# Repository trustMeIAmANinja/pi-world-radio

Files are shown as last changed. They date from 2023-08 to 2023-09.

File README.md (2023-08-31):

# Raspberry Pi Retro World Radio

<picture>
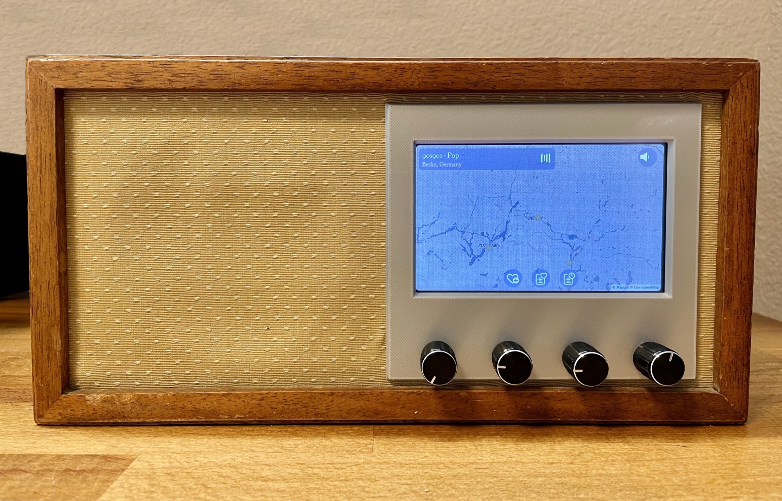
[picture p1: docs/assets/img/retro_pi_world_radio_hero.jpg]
  
</picture>

## What is this?

A retro radio to tune-in to streaming stations from around the world.

## Looking for Docs?

The build docs are here: [https://trustmeiamaninja.github.io/pi-world-radio](https://trustmeiamaninja.github.io/pi-world-radio)

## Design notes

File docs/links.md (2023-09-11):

# Links

A collection of websites and other resources used.

 - [Raspberry Pi OS Docs](https://www.raspberrypi.com/documentation/computers/getting-started.html#installing-the-operating-system ':target=_blank')
    - [Installing the OS](https://www.raspberrypi.com/documentation/computers/getting-started.html#installing-the-operating-system ':target=_blank')
 - [Dave Steele's Comitup - Headless Wifi Manager for Raspberry Pi](https://davesteele.github.io/comitup/ ':target=_blank')
 - [Raspberry Pi OS dtoverlay](https://www.raspberrypi.com/documentation/computers/configuration.html#part3 ':target=_blank')
 - [zram Config to extend life of the SD Card](https://github.com/ecdye/zram-config ':target=_blank')
 - [Raspberry Pi GPIO Pinout @ Pinout.xyz](https://pinout.xyz/ ':target=_blank')
 - [Henryk Plötz's superb article on using a rotary encoder](https://blog.ploetzli.ch/2018/ky-040-rotary-encoder-linux-raspberry-pi/ ':target=_blank')
 - [Raspiaudio HAT Installation Guide](https://forum.raspiaudio.com/t/mic-installation-guide/17 ':target=_blank')
    - [Raspiaudio Pinout](https://pinout.xyz/pinout/raspiaudio_audio_speakers_mic ':target=_blank')
 - [Elecrow Wiki page for the 5" display](https://elecrow.com/wiki/index.php?title=HDMI_Interface_5_Inch_800x480_TFT_Display ':target=_blank')
 - [Minimal Install for running Chromium in Kiosk Mode by Sylvain Durand](https://sylvaindurand.org/launch-chromium-in-kiosk-mode/ ':target=_blank')
 - [Flaticons.Net](https://flaticons.net/ ':target=_blank') - Most of the icons used in the interface are from here
 - [Pixaby/@wixin_56k](https://pixabay.com/users/wixin_56k-9838171/ ':target=_blank') - Author of the Vintage Radio illustration on the docs site
 - [Printables/Unknown Author](https://printables.com ':target=_blank') - Source of the Raspberry Pi4 illustraion on the docs site

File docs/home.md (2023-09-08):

# Introduction

This is the documentation on how I built the Raspberry Pi Retro World Radio.

:size=50%

<p><center>
<iframe width="560" height="315" src="https://www.youtube.com/embed/S_21MZz6pgE?rel=0" title="YouTube video player"
       frameborder="0" allow="accelerometer; autoplay; clipboard-write; encrypted-media; gyroscope" allowfullscreen>
</iframe>
</center></p>

## Inspiration

The original idea for this project came from this project on Hackaday -
[Raspberry Pi World Radio](https://hackaday.io/project/174631-raspberry-pi-world-radio ':target=_blank').
The author of that project never released any of the source code and there were
couple of posts on Reddit where people were wondering what would it take to build
something like this. I loved the concept and decided to take a shot at building one.

## The Build

The rest of the docs contains a mixture of detailed instructions and rough notes of
how I built the Retro Pi World radio. The docs and the project is still very much a
work in progress.

## Source Code

All the source code and related files for the build as well these docs are checked in to a github repo
* [Github/trustMeIAmANinja/pi-world-radio](https://github.com/trustMeIAmANinja/pi-world-radio ':target=_blank')

#### Questions/Comments

If you have any questions or need help, please open an
[issue](https://github.com/trustMeIAmANinja/pi-world-radio/issues/new ':target=_blank') and I will do my best to answer you.

#### Contributions

I don't claim to be an expert in JavaScript, HTML/CSS and as such there is room
for improvement in the App thats running on the Rapsberry Pi. I am happy to take in
contributions as PRs to the source code.

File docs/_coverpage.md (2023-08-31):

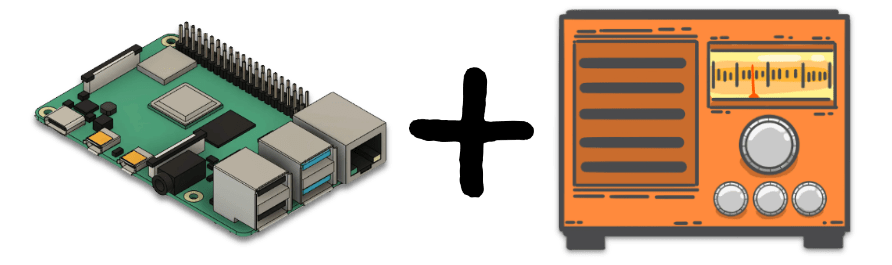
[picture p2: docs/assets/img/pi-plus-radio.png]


# Raspberry Pi World Radio

[Read the Docs](#introduction)
[GitHub](https://github.com/trustMeIAmANinja/pi-world-radio)

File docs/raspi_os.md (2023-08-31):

# Raspberry Pi OS Setup

This page describes setting up the OS for the Raspberry Pi

## Choosing the OS type

Raspberry Pi publishes their own distribution of Linux thats based on Debian and simply
called [Raspberry Pi OS](https://www.raspberrypi.com/software/ ':target=_blank').
It was previously known as Raspbian.

I didn't need a full desktop setup for this build. So I first installed the Lite Version
which doesn't contain any of the packages for the GUI. Later on I installed the minimal
set of packages needed to just launch Chromium. One of the things I wanted was the ability
to manage Wifi connections remotely. For this I found [Dave Steele's Comitup](https://davesteele.github.io/comitup/).
Trying to install Comitup on top of the default Lite install didn't work well because it
required changing the default networking manager. Then i realized that Comitup has its own
pre-configured image of Raspberry Pi OS Lite with Comitup setup. So I switched to using
the Lite Image from Comitup and it worked like a charm.

## Burn the OS to SD Card

Download the Lite Image from [here](https://davesteele.github.io/comitup/ ':target=_blank') and
follow the instructions from
[Raspberry Pi Official Docs](https://www.raspberrypi.com/documentation/computers/getting-started.html#using-raspberry-pi-imager ':target=_blank')
to burn the image to a SD card

When you have the Raspberry Pi Imager open, and after you have selected the image to install,
open the 'Advanced Options' menu and update/set some of the settings

* Enable SSH (though Comitup says its enabled by default in the image)
  * Add your ssh public key if you have that
* Enable 'Username and password'
  * Set username to radio (or anything else you prefer)
  * Set a password
* Enable 'Set Locale settings' and choose appropriate values

Click 'Save' and burn the image. Once done, pop the SD card into Pi and power it up.

?> It will be helpful to have the Pi plugged into a regular monitor and have a keyboard attached at this stage.

## Configure the OS

### Setup Wifi

Following the instructions from [Comitup](https://github.com/davesteele/comitup/wiki/Tutorial ':target=_blank')
and configure the Wifi on the Pi to connect it to a network with Internet access.

If you need to get the IP Address of the RPi on the Wifi and you don't have a keyboard and monitor attached,
refer to the [Remote Access](https://www.raspberrypi.com/documentation/computers/remote-access.html ':target=_blank')
section of the Raspberry Pi Docs.

?> The rest of the instructions for this build assumes the Pi has access to the internet and you can SSH to the Pi
   to run commands in a shell.

### Install additional software

```bash
sudo apt install git python3-setuptools python3-venv xdotool unclutter chromium-browser \
  xserver-xorg-video-all xserver-xorg-input-all xserver-xorg-core xinit x11-xserver-utils \
  fonts-noto-color-emoji
```

?> I use `vim` for editing files when in a shell and installed that using apt. Wherever I use `vim` substitute with
   your editor of choice.

Instructions from NodeSource to [install NodeJS](https://github.com/nodesource/distributions#debinstall ':target=_blank')

```bash
curl -fsSL https://deb.nodesource.com/setup_18.x > /tmp/setup_18.x.sh
sudo -E bash /tmp/setup_18.x.sh && sudo apt-get install -y nodejs
```

!> Always be wary of downloading scripts and directly piping to bash. Unless you absolutely trust the source,
   always download the script and review the code before executing it. In the command above, make sure you review
   `/tmp/setup_18.x.sh` before executing it.

### Autologin

Using `raspi-config` I configured the only user `radio` to be logged in automatically.

```bash
sudo raspi-config
```
System Options -> Boot / Auto Login -> Console Autologin.
Move the selection to 'Finish' using the TAB key and hit ENTER. Choose 'Yes' for reboot and verify on next boot you
are auto logged in to the console.

## OS Tweaks

### Setup Zram

During the normal operation of the OS, there is constant writing of logs and these writes typically go to /var/log
and on the Pi thats going to `/var/log`. Over time the constant write is known to cause SD Card failures. For my
use-case I don't care much for logs and decided to setup a ZRAM drive that will put all log writes to RAM instead
of the SD Card. The downside is anything written to ZRAM will be lost on a reboot, unless you explicitly sync it
back to disk.

Follow the instructions at [https://github.com/ecdye/zram-config](https://github.com/ecdye/zram-config ':target=_blank')
to setup ZRAM.

### Set hostname

Comitup by default sets the hostname and the Wifi AP to something like `comitup-nnn`. I changed it to show something
    more suitable.

```
sudo vim /etc/comitup.conf
```
Change the `ap_name` config key to your preference. I changed it to `pi-radio`.

```
sudo vim /etc/hostname
```
Change the hostname in this file to match what you want. Reboot to pick the changes.

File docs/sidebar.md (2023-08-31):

<!-- markdownlint-disable-next-line first-line-heading -->
- [Home](home)
- [Bill of Materials](bom)
- [Raspberry Pi OS Setup](raspi_os)
- [Hardware Setup](hardware_setup)
- [Frontend Setup](frontend)
- [Assembly](assembly)
- [Links](links)

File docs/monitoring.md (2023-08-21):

# Monitoring and Dashboard

The Pi4 is a much more capable board and I felt had headroom to run other services in the background. 
One such service I wanted to play with  
?> This section is completely optional and does not affect the core functionality of the Pi World Radio.

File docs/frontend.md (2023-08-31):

# Frontend Setup

This page describe setting up the frontend app that displays on the screen of the radio.

## Features

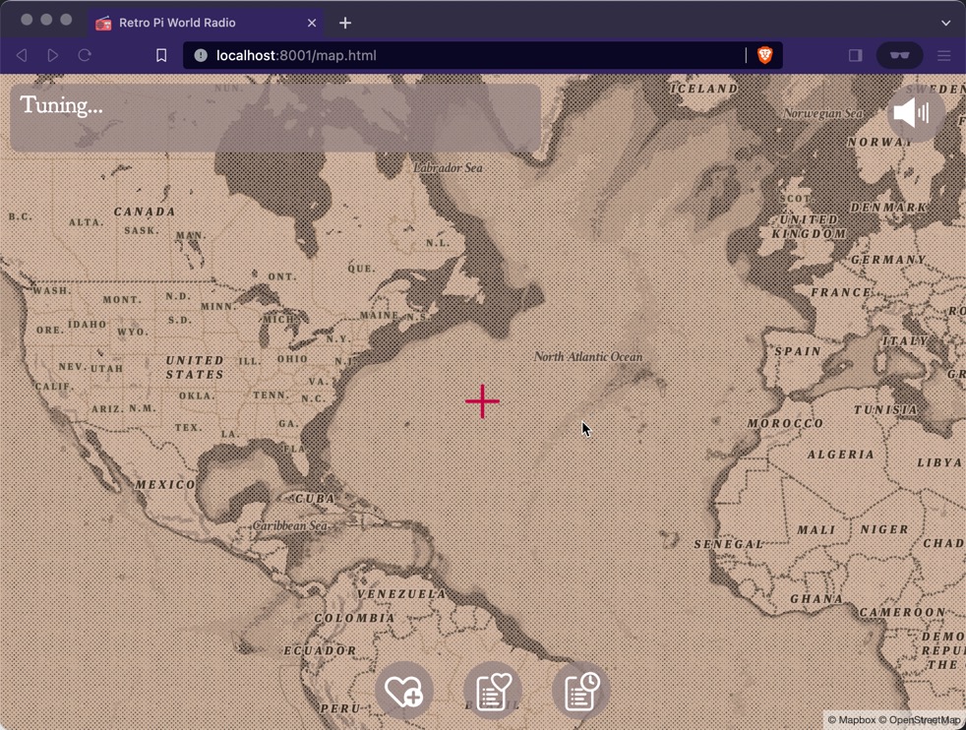
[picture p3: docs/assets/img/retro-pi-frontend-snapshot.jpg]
Frontend app running in a regular browser


The app that runs in the display is a web-app and is loaded into a Chromium browser instance running fullscreen
in Kiosk Mode. There is also a backend component built in NodeJS that serves both the static content for the web
app and has some core functionality needed for the app.

The frontend has a bunch of features beyond the core ability to browse the map and play radio streams
 * Manage your favorite stations
 * Show list of favorite stations (sorted by distance from current center)
 * "Fly" to the location of a station when selected from favorites
 * View history of the last 10 stations played (does not persist on restarts)
 * Turn off the display when idle or with an input combo and turn it back on any input.
 * Plays "tuning" sounds when browsing and nothing is playing
 * All input is via the rotary knobs and the click of the knobs.

The backend
 * is a proxy for the making the calls to radio.garden to get data about channels and streams
 * provides a simple API for the favorites feature
 * provides a simple API to handle the GPIO interaction for turning the display on/off via the relay.
 * (coming soon) will provide API to reboot/power-off the RPi.

## Data Sources

### Location and Stations Data

All the data about locations with radio stations and stations at a given location come from
[Radio Garden](https://radio.garden ':target=_blank'). I download and keep a local copy of the list of locations
from Radio Garden. This is a large dataset and doesn't make sense to query every time. When you browse to a
location that has stations, the frontend queries Radio Garden for a list of stations for that location. The
frontend cannot make this query directly because of CORS restrictions and uses the backed as a proxy to get the
data. Finally when you choose a station to play, it again makes a direct request to Radio Garden which redirects
to the streaming url for that station and thats loaded into the audio player in the browser.

?> I am aware that using Radio Garden this way is very likely violating their TOS. If you are not comfortable with
   this, I would recommend you find a different way of obtaining the data.

### Maps

I use [Mapbox GL](https://docs.mapbox.com/mapbox-gl-js/guides/ ':target=_blank') and the vintage style theme from
[mapbox-gl-vintage-style](https://github.com/mapbox/mapbox-gl-vintage-style ':target=_blank') to create the map
interface. The offline Radio Garden data is loaded as a map "layer". Mapbox has a generous free tier and this app
barely causes a scratch in the free tier quota.

## Mapbox Setup

Create an account with [Mapbox](https://mapbox.com ':target=_blank'). Next get your access token for using the
API from your account [dashboard](https://account.mapbox.com/ ':target=_blank'). You will use this token later
in the app code.

To create the vintage map style, clone this github repo - [mapbox-gl-vintage-style](https://github.com/guillermodlpa/mapbox-gl-vintage-style ':target=_blank')
and follow the instructions in the repo to create your vintage style.

## Update The App Source Code

If you haven't cloned the [pi-world-radio](https://github.com/trustMeIAmANinja/pi-world-radio ':target=_blank')
repo to your home directory on the Raspberry Pi, do it now.

```bash
git clone https://github.com/trustMeIAmANinja/pi-world-radio ~/pi-world-radio
```

Edit the file `app/public/assets/js/app.js` in the cloned repo and update a couple of lines. Look for this section
in the file

```javascript
mapboxgl.accessToken = ".................................................................."
const map = new mapboxgl.Map({
  container: "map",
  style: "mapbox://styles/wrecker/clkz7vn0000n301pb1mtjho13",
  center: [-53, 35.2],
  zoom: 2.2,
  minZoom: 2.05,
  maxZoom: 12,
});
```

Replace the `......` inside the quotes with the access token from your account. Change the style attribute to point
to your version of the vintage style.

## Add Service To Run The Backend

```bash
sudo cp ~/pi-world-radio/files/etc/systemd/system/pi_radio_app.service /etc/systemd/system
sudo systemctl daemon-reload && sudo systemctl enable pi_radio_app.service.service
```

?> Make sure you update the various paths inside the service definition to match your setup

## Setup Chromium Kiosk Mode

Earlier during the OS setup, you should've installed the required packages to run X apps but no window manager or
desktop packages. Its possible to simply run a X app (like Chromium) with this setup. This way we reduce the
resources used when running the usual X desktop.

Add the `.xinitrc` file to launch chromium in kiosk mode

```bash
cp ~/pi-world-radio/files/.xinitrc ~/.xinitrc
```

Add this to the end of `~/.bashrc` on the RPi (if using bash as thr login shell).
```
if [[ ! $DISPLAY && $XDG_VTNR -eq 1 ]]; then
  startx
else
  echo "Not starting X"
fi
```

Again reboot the RPi. If everything was setup correctly after booting up you should see the browser
startup and load the radio app in fullscreen.

### Additional features

If at any point you want to restart the browser, add this file `~/.restartkiosk` and it will cause the browser to
stop and restart. Useful to reload the app after making any changes. The file will be automatically deleted.

```bash
touch ~/.restartkiosk
```

If at any point you want to end the browser session and get to the prompt on the console add file `~/.nokiosk`.
Again this file will get cleaned up automatically.

```bash
touch ~/.nokiosk
```
Both of these files can be added from an ssh login session.

To start the app again, run `startx` on the console. You cannot run `startx` from an ssh session.

## Debug The App

If you are having issues with the app and need to debug it, you can load the app in a browser on you laptop with
this url `http://<rpi-ip-address>:8001/`. Use the developer console to view any errors in the browser console.

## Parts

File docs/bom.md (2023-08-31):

This is the breakdown of the hardware that went into the final build. There are additional
pieces that I used in the process of building that I already on hand. Those are also
listed in the next section.

## Bill Of Materials

All the prices listed here are what I paid for them (before any taxes/shipping) and don't reflect current pricing. Links do not contain any affiliate marketing code.

| Item | Price | Link | Notes |
|---|---|---|---|
| Raspberry Pi 4 2GB | $45 | https://www.adafruit.com/product/4292 | |
| RaspiAudio DAC HAT | $25 | https://www.amazon.com/dp/B09JK728MB | |
| 5" Screen | $26 | https://www.amazon.com/dp/B07NRYPZM1 | |
| USB-C 20W Power Adapter & Cable | ~$10-$15| | I had a couple of spares. Any good 20W adapter and usb-c cable will work |
| 32GB Micro SD Card | $6 | https://www.amazon.com//dp/B08J4HJ98L | Came as a 2-pack for $12 |
| 270 Degree HDMI Adapter | $5 | https://www.amazon.com/dp/B0BWHHSMTZ | the 270 Degree is important because of how the HDMI port on the screen is oriented |
| Micro HDMI Adapter | $5 | https://www.amazon.com/dp/B07K21HSQX | Came as a 2-pack for $10 |
| Short HDMI Cable | $9 | - | Had one lying around |
| Heatsink for Rpi 4 | $7 | https://www.amazon.com/dp/B08N5VZN8R | See Notes |
| GPIO Extender | $9 | https://www.amazon.com/dp/B0BDF48FWM | Needed to install Audio HAT on top of heatsink |
| 40pin Male to Female GPIO Cable | $4 | https://www.amazon.com/dp/B07CGM83QL | Came as a 2-pack for $8 |
| Thermal Compound | $5 | | Don't use the thermal stickers that come with the heatsink. Any quality thermal compound typically used in PC builds will work |
| Relay Module | $7 | https://www.amazon.com/dp/B0057OC6D8 | Only one channel was used, but was cheapest option that didn't require buying a bundle |
| Donor Radio Box | $30 | Ebay - KLH Model Twenty One | See Notes |
| Vintage Grill Cloth | $12 | Etsy | Search for Vintage Speaker Grill cloth |
| 4" Midrange Speaker | $25 | https://www.amazon.com/dp/B00RC3Z9H2 | See notes |
| Spare wood or board for front face | - | - |Had some leftover board. Might be able to find something free/cheap in the discard bin in any home improvement store |
| Rotary Encoders | $10 | https://www.amazon.com/dp/B07FJQH1F7 | |
| Assortment of M2.5 and short screws | - | Depends on how you mount the hardware |
| Small Angle Brackets | $2 | - | |
| Wires | - | - | I used jumper wires that i got with the rotary encoders for most of the wiring |

### Notes

 * Heatsink: The Raspberry Pi4 tends to run a little hotter than previous boards. During development
   I saw idle temp of around 52&deg;C and it would rise once I started running chromium and playing
   audio. Since the board was going to be in an enclosed box, I decided to put a good quality
   heatsink to help with cooling. Using quality thermal compound and the head-sink, I immediately
   saw idle temps go down to 40-41&deg;C and even under normal load it never went above 50&deg;C
 * Donor Radio: I was looking for an old radio where the speaker was off to the side and there is
   enough room to cutout a window to embed the 5" screen. The model in the original Hackaday
   project would've been perfect but I couldn't find it on ebay or other sites. So I kept searching
   ebay for "vintage radio" and came across the [KLH Model Twenty One](https://www.radiomuseum.org/r/klh_klh_twenty_one_21.html ':target=_blank')
   This particular model looked very much like what I was looking for and I got lucky when I found
   a listing where it was being sold for cheap because it was not working. My original plan was to re-use
   the front face that came with the donor radio. But the placement of the screen in the original board would
   make the existing holes for the knobs off-center. I also decided I wanted to use a fourth rotary knob. I
   decided to make a new front face with some leftover board pieces I had lying around. Ultimately it might
   have been cheaper to simply build the whole box. Anyways atleast I can claim I used the bones of a real
   vintage radio.
 * Speaker & Grill Cloth: You maybe able to source this on the cheap if you go hunting in thrift stores for
   old spearkers and salvage the cloth and decent speaker drivers.

## Other Materials for Development

These are the materials that I used when testing out the build and developing the software.

 * Breadboard
 * Lots of jumper wires
 * 40-pin Breadboard GPIO Extender
 * Electrical wires

## Tools

The tools I used

 * Dremel Rotary tool
 * Drill machine and drill bits
 * Sander and blades for Dremel
 * Digital Multimeter
 * Soldering Iron and Solder
 * Wire Stripper
 * Scissors
 * Super Glue, hot glue and glue gun.
 * 91% Isopropyl Alcohol.
 * Precision Screw driver set
 * Digital Calipers
 * Autodesk Fusion 360 for designing the 3D parts and laying out the design for the front face.
 * 3D printer (Creality Ender3) for printing the 3D printed parts.

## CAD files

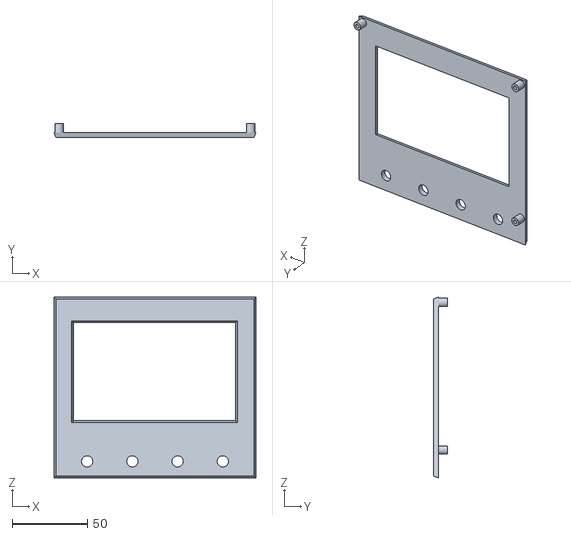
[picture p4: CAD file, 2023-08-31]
3d-print/pi_retro_radio_front_face.stl
134.0 x 9.50 x 120.0

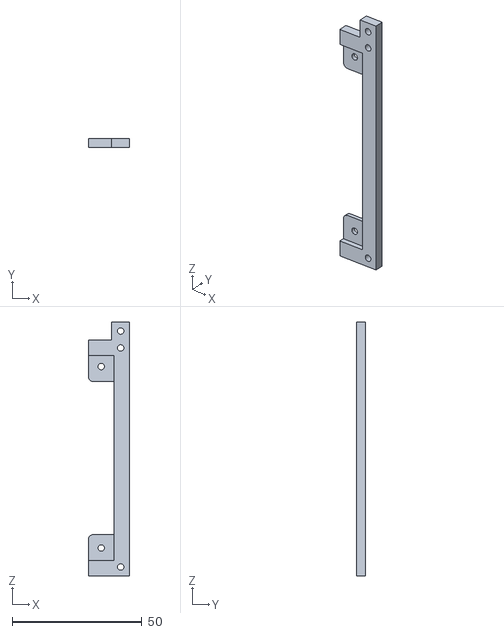
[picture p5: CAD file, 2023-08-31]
3d-print/pi_retro_radio_screen_mount_left.stl
16.0 x 3.50 x 98.0

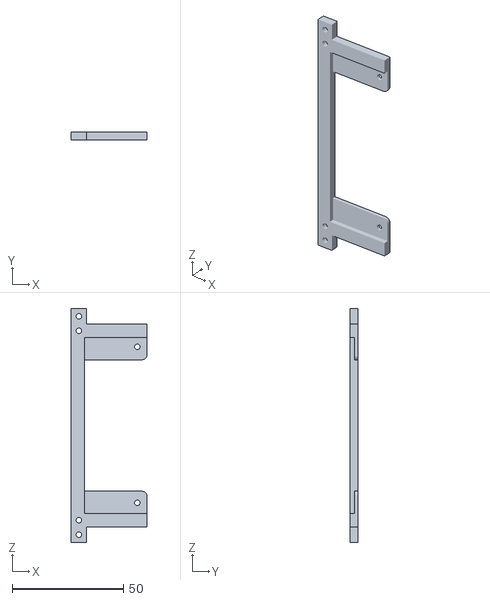
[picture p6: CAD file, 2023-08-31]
3d-print/pi_retro_radio_screen_mount_right.stl
34.0 x 3.50 x 105.0

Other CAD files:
3d-print/PiRetroRadio.f3d

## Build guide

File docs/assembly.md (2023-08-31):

# Assembling The Hardware

This page describes the final assembly steps to put together the Pi Retro World Radio.

## Front Face

### Backing Board

I used the original backing board to trace and cut a similar sized piece from a piece of board.

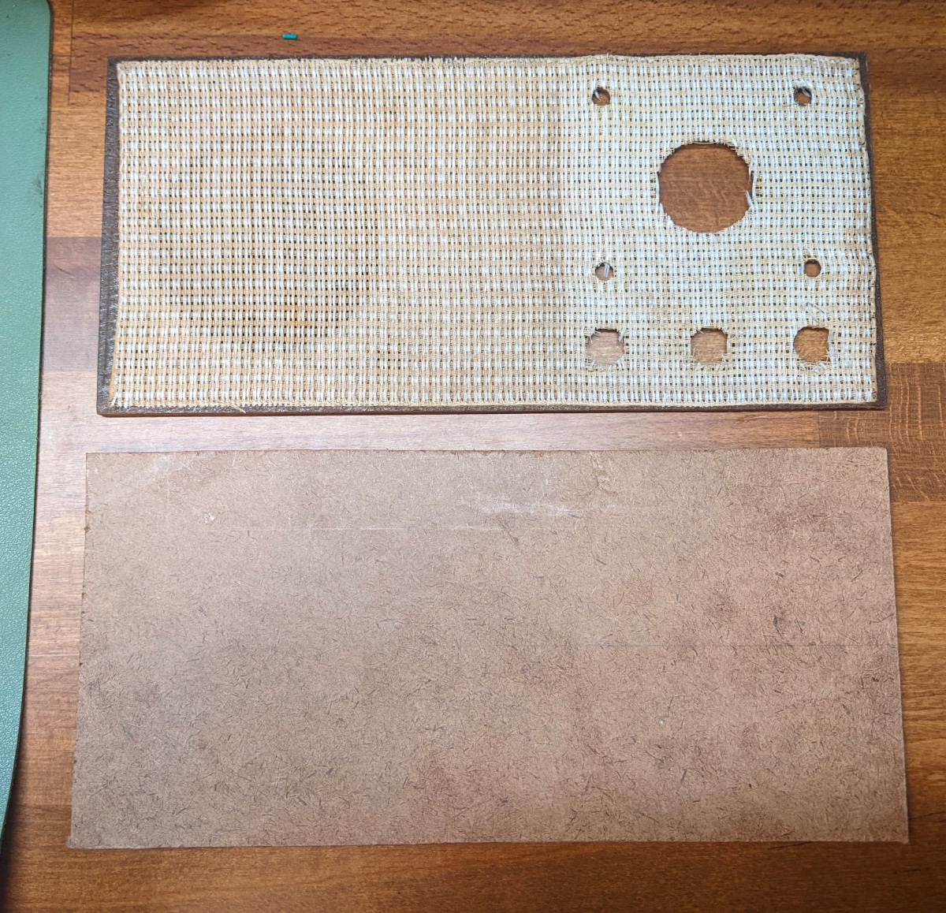
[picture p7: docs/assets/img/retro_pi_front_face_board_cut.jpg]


I created this sketch in Autodesk Fusion 360 to help me create the 3D design for the 3D Printed pieces. I
just added some additional dimension annotations and used that to make the cutouts and drill holes on the
board

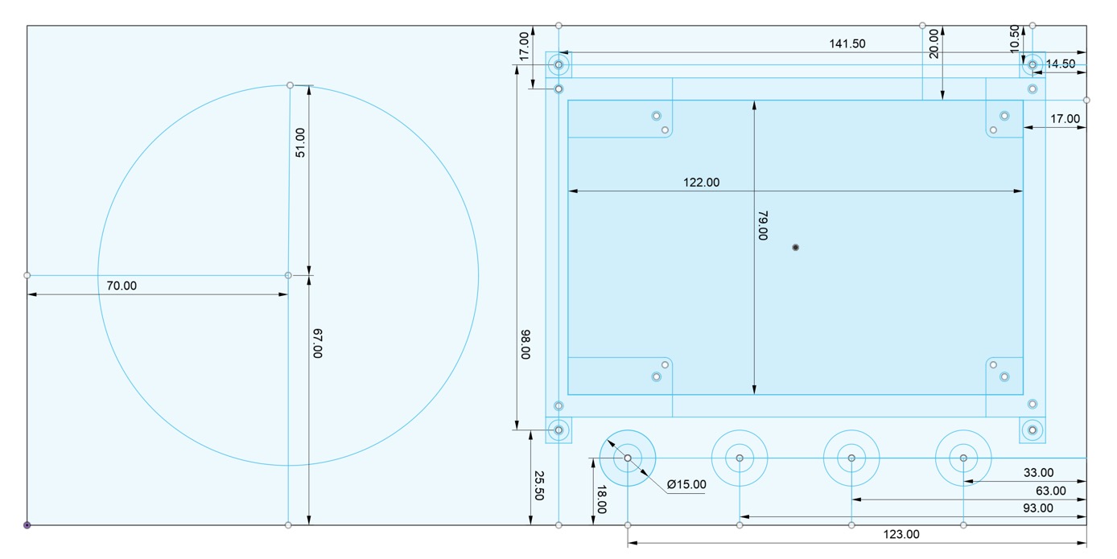
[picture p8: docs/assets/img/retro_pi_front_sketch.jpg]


I used a small bit to drill lots of tiny holes close to each other for the speaker and display cutout. Then
using a dremel and a small circular blade I cut out the pieces and then sanded down the rough edges. Also marked
and drilled holes for the rotary encoder and for the 3D printed front piece.

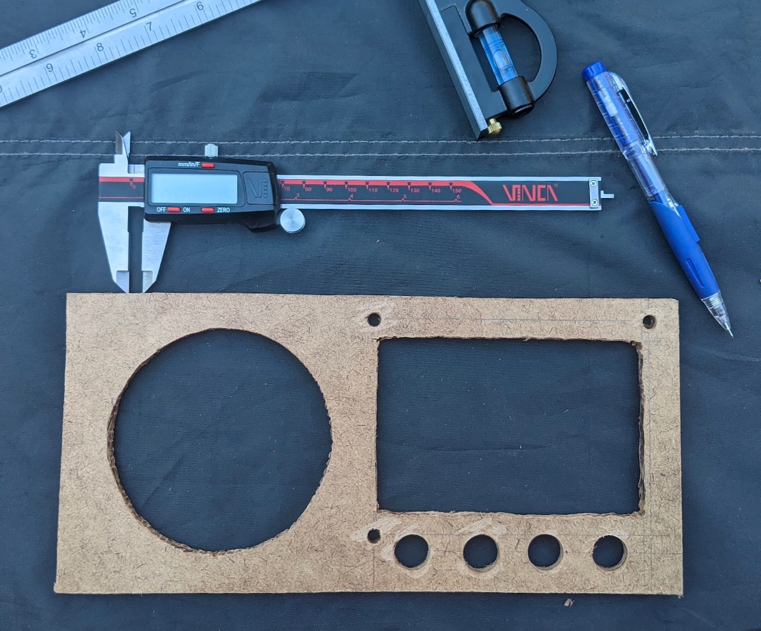
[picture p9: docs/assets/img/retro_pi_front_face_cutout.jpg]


### Grill Cloth

Using the board with the cutouts I marked the backside of the the vintage cloth to cut that. I only cutout the
part where the display will come through. For the rotary knobs I used a sharp object to punch the holes and also
the holes where the 3D printed piece will poke through. I used super glue to carefully glue the cloth onto the
board.

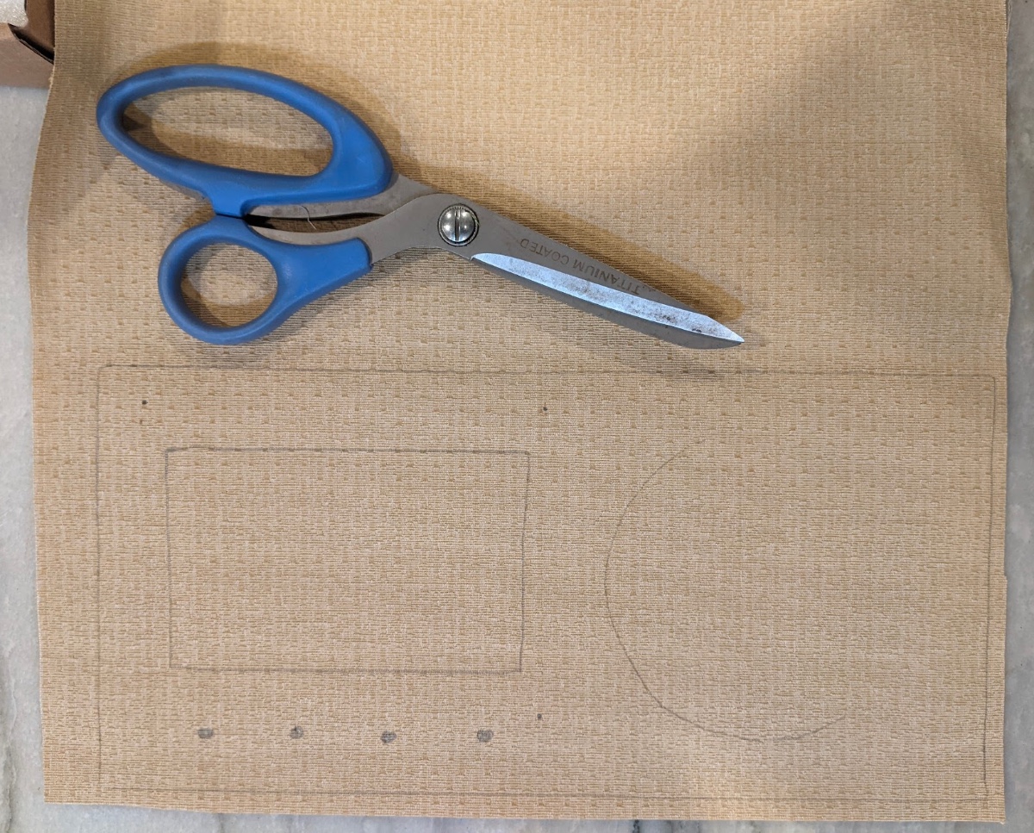
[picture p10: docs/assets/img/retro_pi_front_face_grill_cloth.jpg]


### 3D Printed Front Frame

I designed and 3D printed a front frame for encoder + display area. There is a correspoding back frame that attaches
to the display and to the front frame to hold it all together. You can find the 3D files and Fusion 360 project in
the github repo.

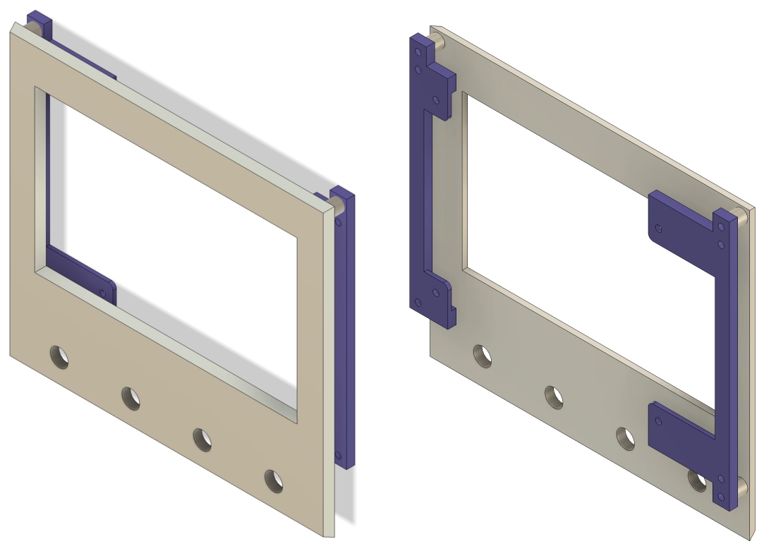
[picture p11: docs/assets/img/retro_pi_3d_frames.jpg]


### Mounting Inside The Box

This was a bit of challenge. The original radio had an an inner aluminium frame and the front face board was mounted
to it. I couldn't use that, so I had to improvise and figure out a way to securely mount the new front face. I
eventually decided to use small 90-degree angle brackets that would be screwed to the side walls of the box. First I
had to mark the points where the brackets would be screwed with the board inside. With a drill bit at an angle I
made some starter holes. Then I used self-tapping screws to "drill" holes in the soft wood of the box. Finally I
put the board back in and installed the angle brackets to hold it in. I used two on the speaker side and 1 on the
other side.

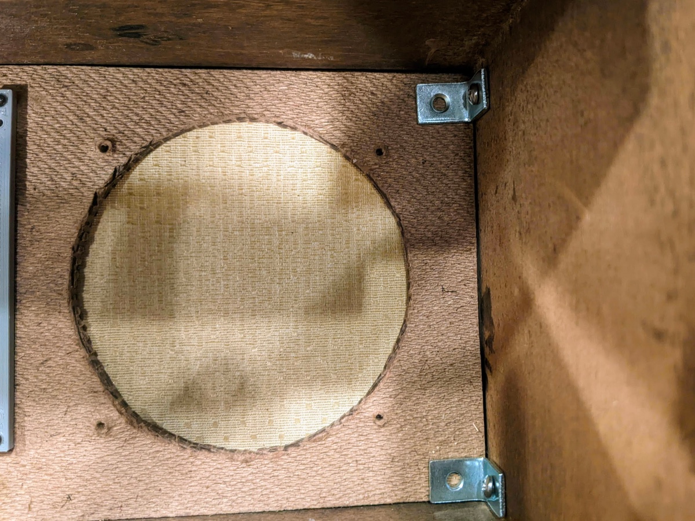
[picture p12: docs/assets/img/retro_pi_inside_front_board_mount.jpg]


## Display

The display didn't have any mounting points to attach it to the back of the backing board. I had to improvise a bit
here. I sketched and designed frame prices that would go over the 4 standoff screws on the back of the display and
extend out to attach to the board. I then extended the design to allow the front 3d printed frame to attach to
these back frame pieces and overall I got a really good mount. I screwed the standoffs that came in the display box
to the keep the display attached to the frame pieces. I attached the 270 degree HDMI adapter to the display, a
regular HDMI cable to this which was then attached to the micro-HDMI to HDMI adapter from the RPi.

## Rotary Encoders

Using a soldering iron I de-soldered and removed the header pins that come on the rotary encoder boards because they
made it almost impossible to mount the encoders to the backing board. I soldered the jumper wires to the back of the
rotary encoders modules. Because the jumper wires were a bit too thin, I put a blob on hot glue on the wires to
prevent them from breaking off.

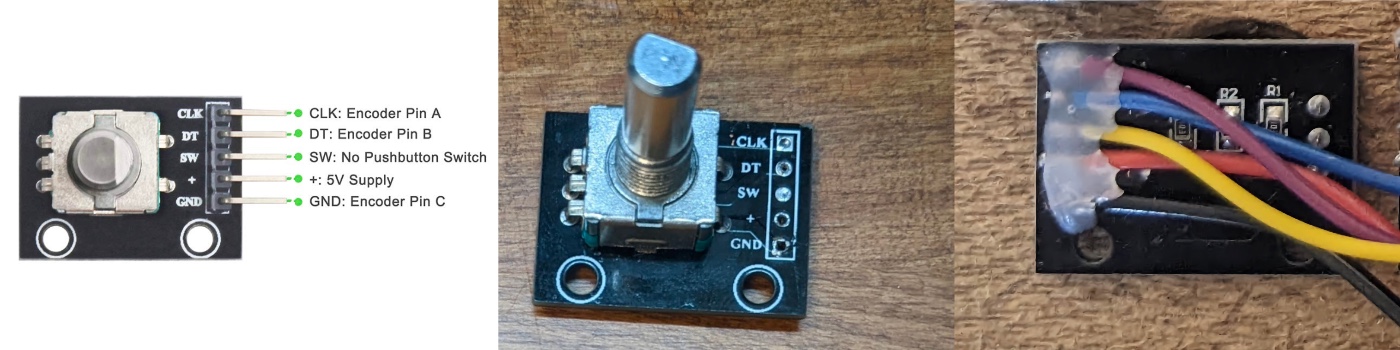
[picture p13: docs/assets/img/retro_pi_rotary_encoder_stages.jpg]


The rotary encoders were pushed through the back side and on the front I used the washers and nuts that came with
them to securely mount them to the front frame.

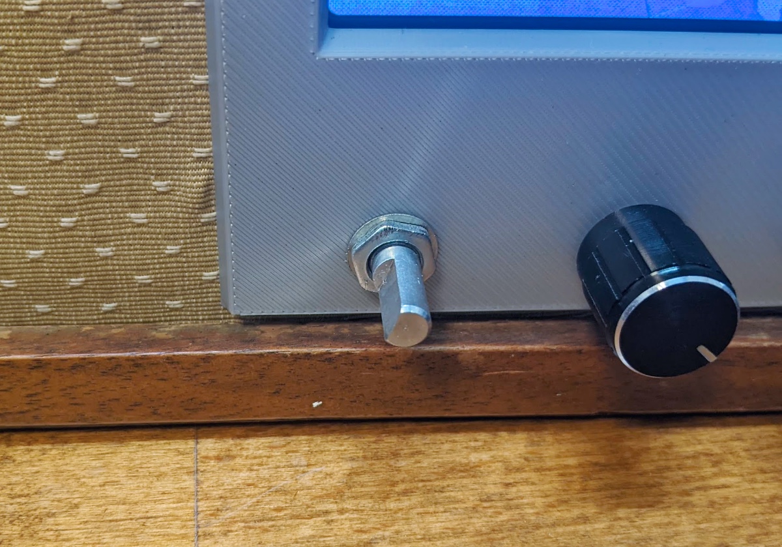
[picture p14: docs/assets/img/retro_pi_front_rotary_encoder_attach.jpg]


On the back side, I soldered the signal wires from the encoders to the solder pads on the back of the display.
These pads will eventually connect to GPIO header of the RPi when the GPIO ribbon cable is attached. Refer to the
pin mapping in the [hardware setup](hardware_setup?id=rotary-encoders) section. The layout of the solder pads is
mirrored as compared to the GPIO header on the RPi. So triple-check before you solder them. I took the +V and GND
connections and bunched them together and then attached a single wire to the GPIO point. I used heatshrink tubing
to secure the joints.

?> All the soldering was done with the front face board outside the box and then I carefully re-mounted the board
   back into the box.

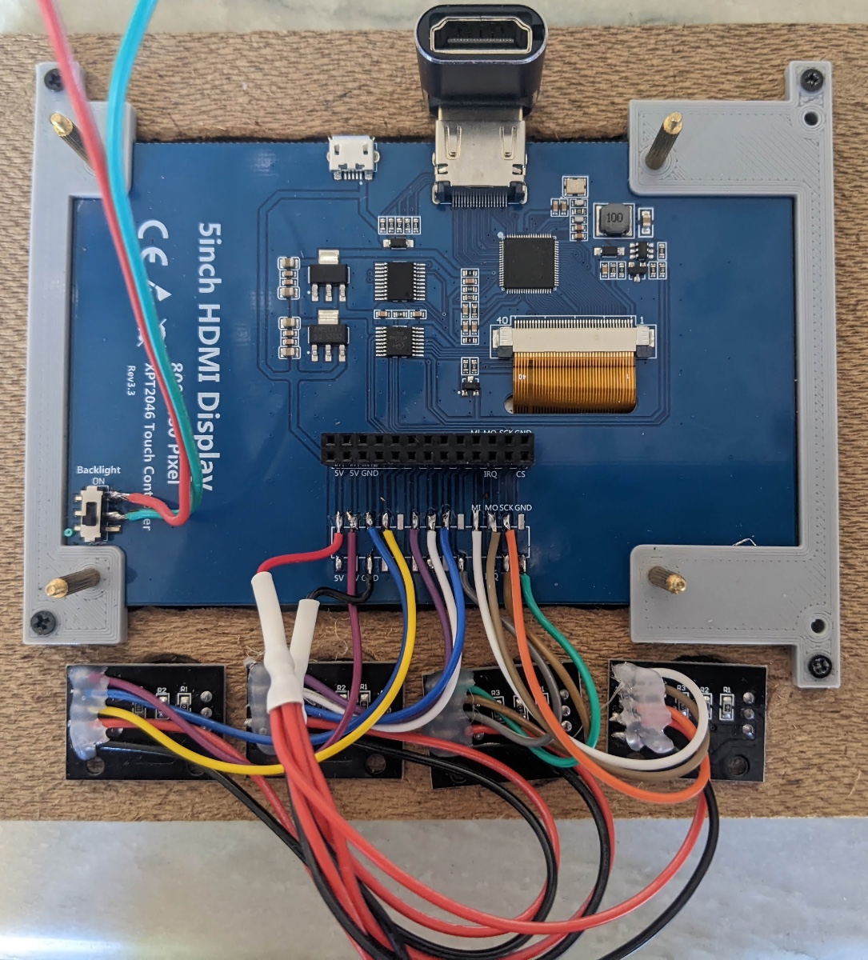
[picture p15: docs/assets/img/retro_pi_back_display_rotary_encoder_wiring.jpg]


## Speaker

To mount the speaker to the board, I looked for the shortest self-tapping screws in the hardware store. These were
a bit too long and would've poked through the grill cloth. So I added a couple of washers to keep the screws from
poking through and still hold securely to the board.

## Raspberry Pi

The heatsink for RPi came up 4 screws and 4 brass standoffs. During the development phase I used the screws from
the bottom to hold the heatsink down. For mounting the RPi into the radio box, I marked the four holes for the
mounting points on the bottom of the box and drilled four holes with a small drill bit from the outside through
the wood on the bottom. Using a bit of force i threaded the brass standoff from the inside. This gave me a nice
secure way to mount the RPi inside the radio box and the space under the board helps with ventilation and cooling
of the board.

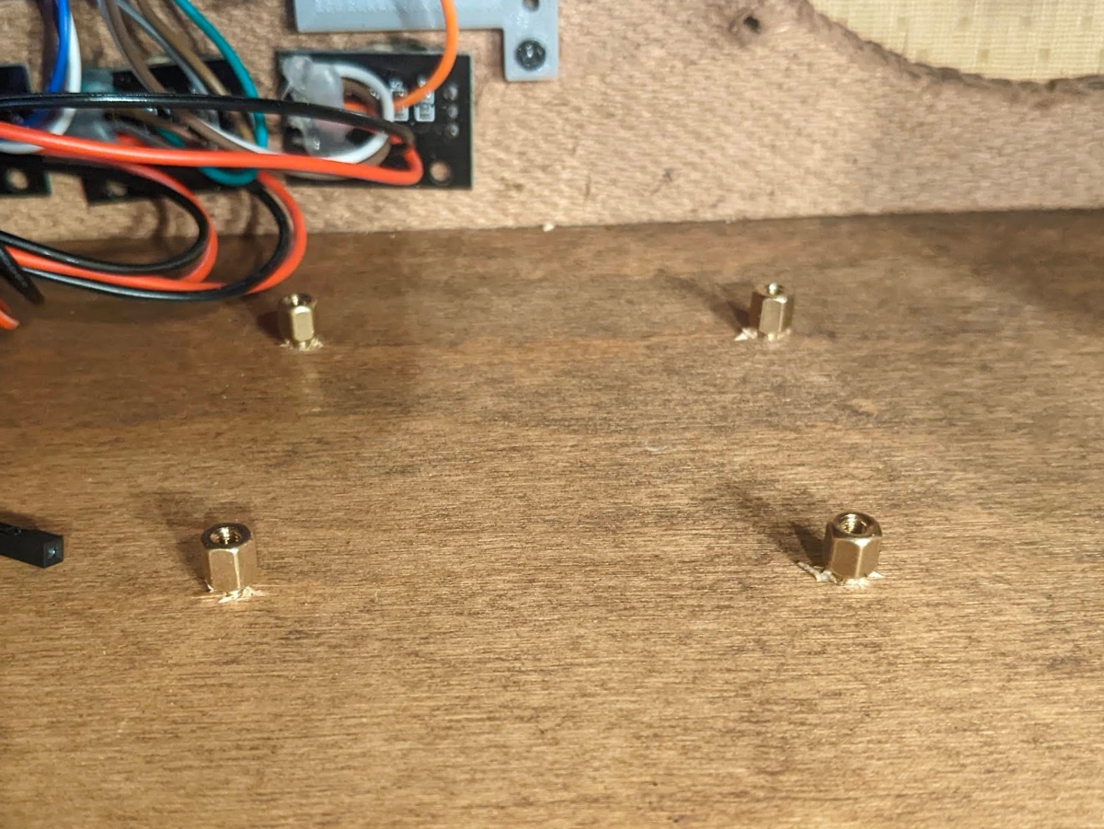
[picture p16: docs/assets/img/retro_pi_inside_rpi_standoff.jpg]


I unscrewed the heasink and thoroughly cleaned and removed the old thermal grease with some isoproply alcohol. I
re-applied fresh thermal grease and put the heasink back on. This time I put the screws from the top and screwed
them into the brass standoff.

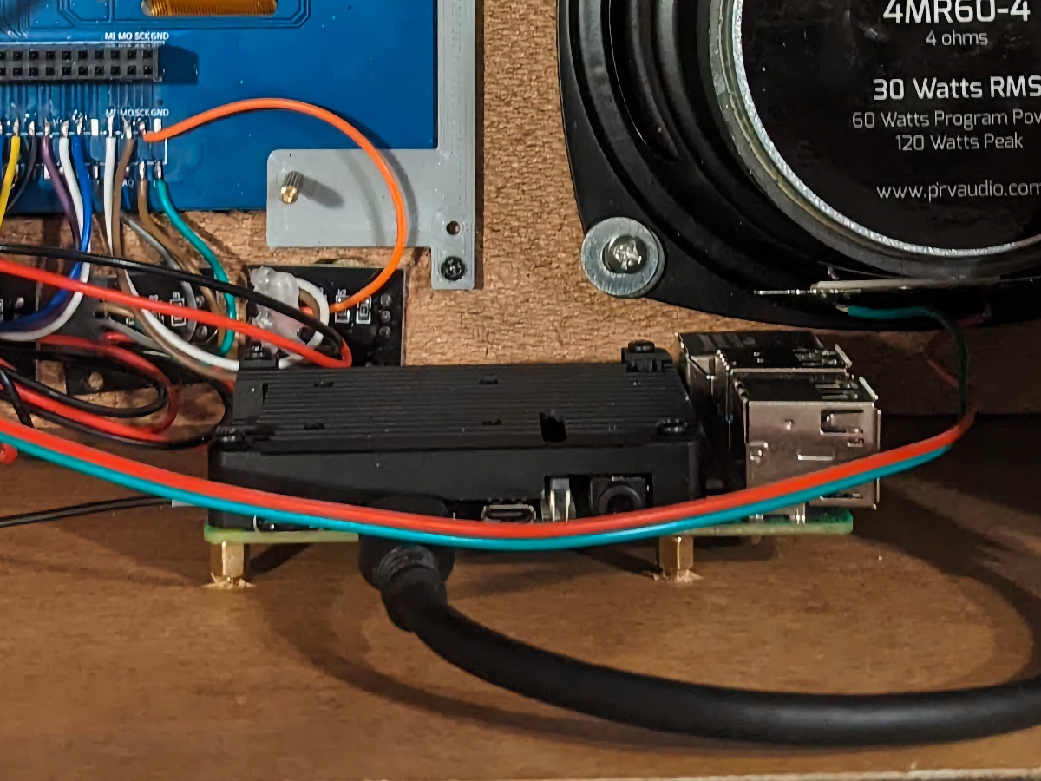
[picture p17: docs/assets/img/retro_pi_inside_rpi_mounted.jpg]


## AudioHat & GPIO Cable

The Audiohat plugged onto the GPIO header pins on the Pi and is fairly secure. It has a similar male header pins
on the top. I attached the 40-pin female-to-male GPIO ribbon cable between the headers on the Audiohat and the
26-pin female header block on the back of the display. This gets the +5V power needed for the display and forwards
the GPIO all the way to the solder pads on the back of the display where everything else is soldered on. The
wires from the speaker were screwed to one set of terminals on the Audiohat.

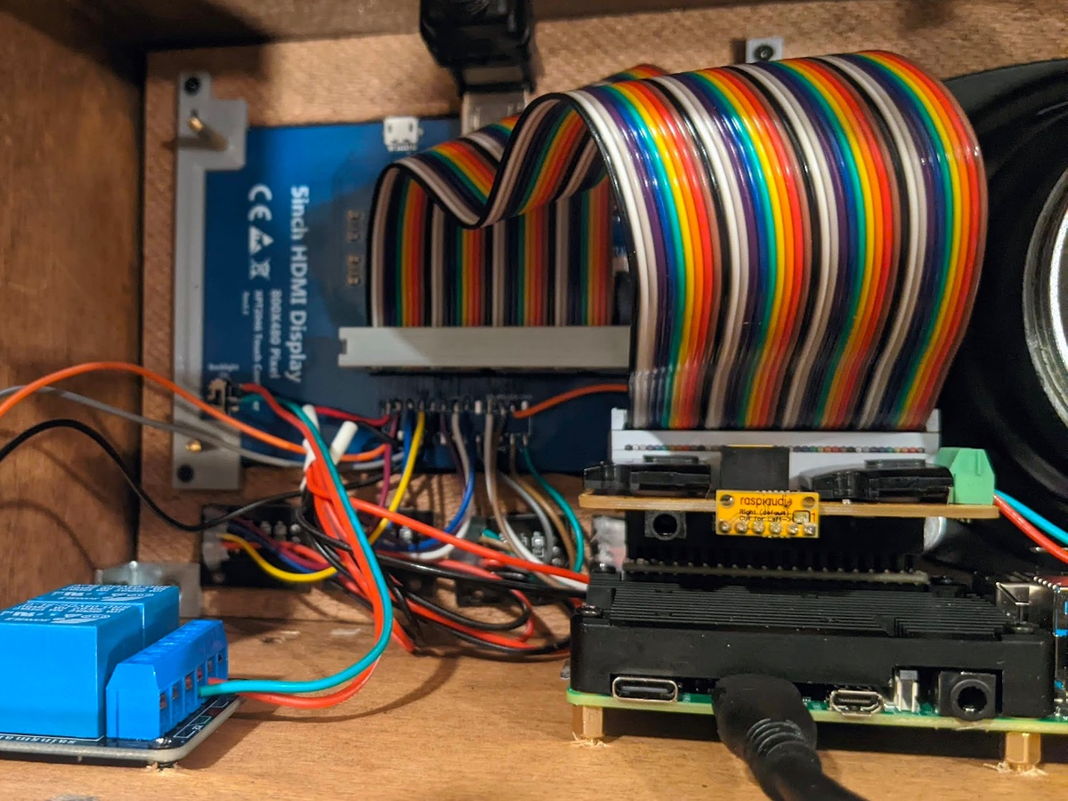
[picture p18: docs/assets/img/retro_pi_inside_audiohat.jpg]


## Relay Board

One of the images above shows how I soldered the wires to the display backlight on/off switch. I soldered jumper
wires for the relay signalling to the solder pads on the back of the display. On the relay board side I attached
the jumper wires to the header pins and put a dab of hot glue to keep them from moving. I screwed the relay board
down to the base of the radio with some M2.5 screws and attached the wires from the display switch to the normally
open terminals.

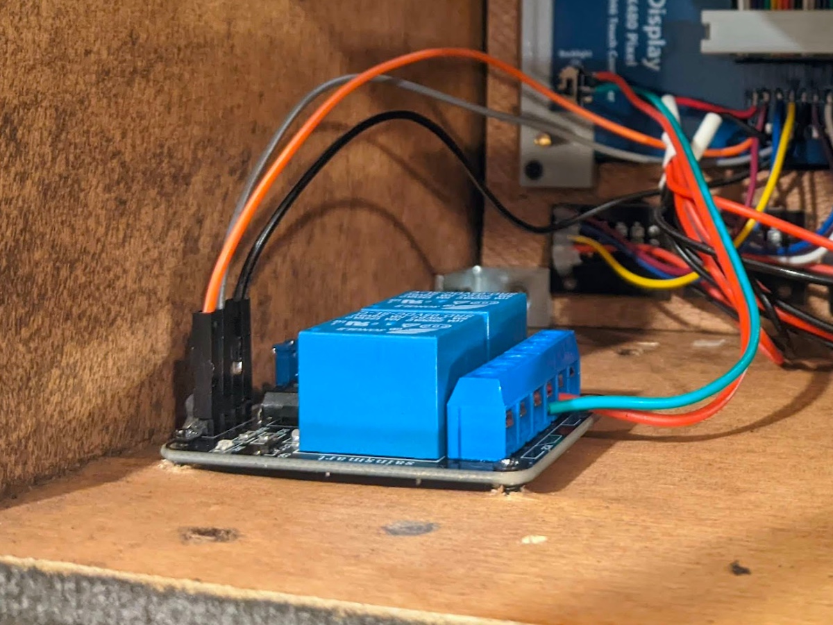
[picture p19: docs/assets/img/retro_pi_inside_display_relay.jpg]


## Power Up!

Thats it. I closed up the back with the original cover and was able to attach the usb-c power via the cutout that
was already in the back cover.

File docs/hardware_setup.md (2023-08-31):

# Hardware Setup

This page describes all the steps to get the various hardware components working.

## Components

### Heatsink

Mounting the heatsink is pretty straighforward. It came with mounting screws and brass standoffs. The
standoffs came in handy later when I had to mount the Rpi inside the radio box. I discarded the thermal
pad stickers that came with the heatsink and used some proper thermal grease. Just a tiny bit of grease is
enough. Make sure to put grease on both the CPU and the RAM chip.

### Audio DAC Hat

Initially, I mounted the Audio DAC Hat, directly on top of the GPIO Header on the RPi. Later when I installed
the Heatsink, the HAT would not sit. I then put the GPIO extender/splitter and put the HAT on top of it.

To disable the onboard speakers on the HAT, I used a blade to cut the solder joints on the board as shown in their
docs. Do this after you have verified everything is working.

### Speaker

I used a 4" mid-range speaker to get a decent frequency coverage and something that would not be too bulky to fit
in the box. Since I am only going to be playing internet streams, I didn't need a high-end audiophile quality driver.
If you can salvage a driver from an old PC speakers they might work as well. I soldered a pair of wires to the
speaker's terminals and then attached them to the speaker terminals on the HAT.

### Display

The 5" HDMI display I chose is pretty basic. It can be powered from the 5V rails on the RPI GPIO headers. I chose this
specific model for a couple of reasons
 * Displays with any kind of onscreen menu and bells and whistles tend to have a startup delay. This one turns on/off instantly.
 * The touchscreen functionality is disabled by default, unless you configure the OS to enable it. I didn't plan to
   use touchscreen and it freed up GPIO ports for other uses.
 * the back of the display has solder pads for the first 26 pins of the RPi GPIO headers and I could use these to wire up
   the encoders and relay

To connect the display, I used the 40-pin male-to-female GPIO ribbon cable and connected the 26-pin header on the
back of the display to the RPi GPIO header via the GPIO extender. Make sure you match the sides correctly so that
the pins are connected correctly. I connected the HDMI port on the display to the RPi using the micro-HDMI to HDMI
adapter.

### Relay Module

The one thing that would've been nice to have in the display was some way of controlling the backlight using GPIO.
Instead it had a simple switch in the back. Once the display is in the box there is no way to access it. A little
testing showed that the switch was wired to the 5V power supply. I could just connect a simple relay in parallel to
the switch and leave the switch in the OFF position. This way I could turn it on/off using software. All of the
simple single channel relay modules required buying a bundle of 3-4 on Amazon. So I opted for the cheapest option,
which turned out to be the dual-channel module I used.

On the relay module, ensure the jumper is connecting the JD-VCC and VCC pins. Connect 5V from the GPIO header to
relay module's VCC Pin and one of the GND pin to GND pin on the relay module. Finally connect GPIO 14 to one of the
channel input pins (IN1 or IN2). Just remember to connect the wires from the display switch to the correct channel's
'Normally Open' terminals.

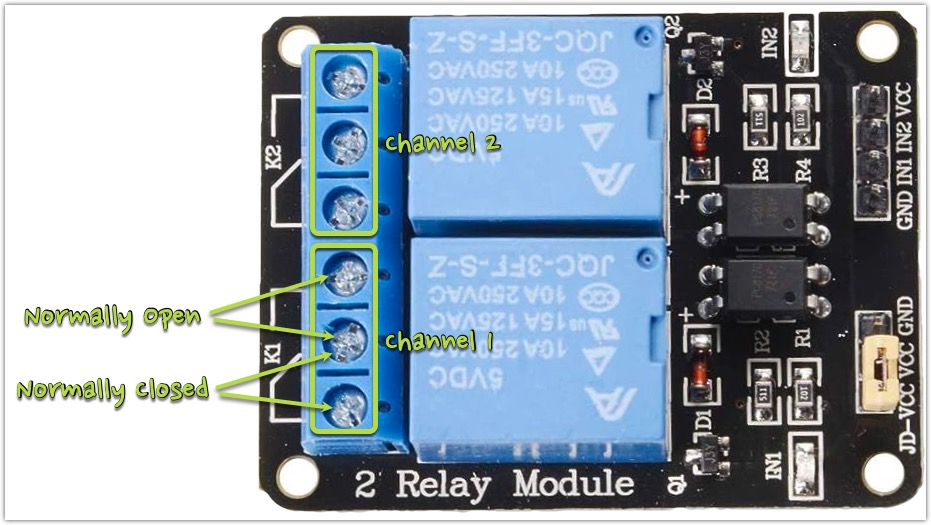
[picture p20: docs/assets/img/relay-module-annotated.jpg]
Relay Module Annotated :size=50%


### Rotary Encoders

Other than the display this is the most visible off all the components and the one that adds the "retro" look. I
had trouble getting them to work reliably using some of the popular tutorials
([here](https://thepihut.com/blogs/raspberry-pi-tutorials/how-to-use-a-rotary-encoder-with-the-raspberry-pi ':target=_blank'))
that used GPIO libraries to read the encoder state to determine rotation. Eventually I found this
[blog post](https://blog.ploetzli.ch/2018/ky-040-rotary-encoder-linux-raspberry-pi/ ':target=_blank') that made it
dead simple to integrate the rotary encoders. The bonus was that the `evdev` python library used for reading the
rotary encoders also had dead simple functionality to emit keyboard events which I was going to do anyways.

The rotary encoders also have a push-to-click button which I use for additional events for the user interface.
This table shows the keyboard events emitted for each action of the rotary encoders.

| Encoder | Rotate Left | Rotate Right | Click |
|---|---|---|---|
| **1** | Left Arrow  | Right Arrow  | q |
| **2** | Down Arrow  | Up Arrow | p |
| **3** | o (zoom in) | i (zoom out) | n |
| **4** | l (vol down) | h (vol up)  | m |

These keyboard events are sent to the active application/window by the OS. That would be the chromium browser in
fullscreen kiosk mode running the web app where the javascript code will handle the events and execute the
appropriate event handler to perform various actions.

This table lists the mapping of the encoder and switch pins to the GPIO Pins. I connected one of the 3v3 pins to
the `+` of the encoder pins.

| Encoder | CLK | DT | SW |
|---|-----|----|----|
| **1** | 10  | 9  | 11 |
| **2** | 7 | 8  | 24 |
| **3** | 17  | 27 | 22 |
| **4** | 2 | 3  | 4  |

?> Note the pin numbers are not the physical pin numbers. I use the excellent [pinout.xyz](https://pinout.xyz/ ':target=_blank')
   to map from GPIO number to physical pin number.

## Development Setup

The first thing I did was to get a development setup going with a breadboard and jumper wires.
Even if you are simply going to follow this build without making any changes, I will still
recommend setting up everything first on a breadboard and get everything working before putting it
all in inside the final box. I used a RPi GPIO to Breadboard extender. You don't necessarily need
this and you can simply connect jumpers from the breadboard to the GPIO pins. The extender was
more convenient because it had labels for the GPIO pins that made it easier. Here's a picture of my
final development setup.

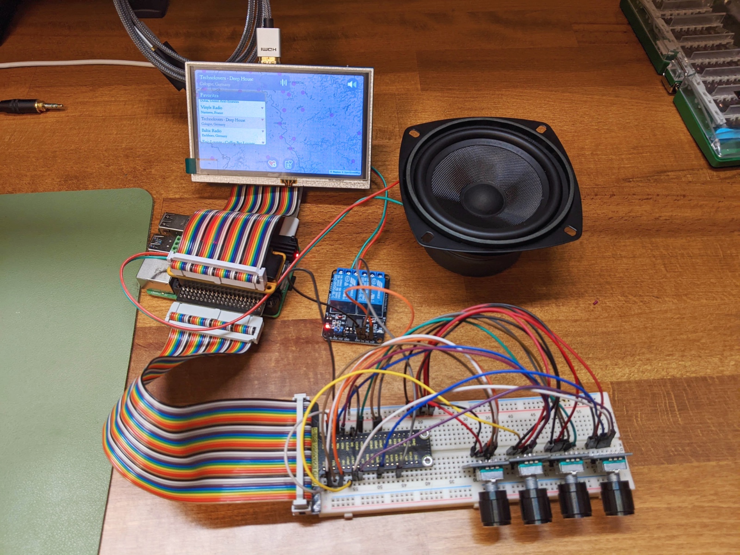
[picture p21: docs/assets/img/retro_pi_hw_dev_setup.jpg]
Hardware Dev Setup :size=50%


## Software Setup

Clone the [pi-world-radio](https://github.com/trustMeIAmANinja/pi-world-radio ':target=_blank') repo to your
home directory on the Raspberry Pi

```bash
git clone https://github.com/trustMeIAmANinja/pi-world-radio ~/pi-world-radio
```

### Audio DAC Hat

Instructions for setting up the RaspiAudio HAT from their
[installation guide](https://forum.raspiaudio.com/t/mic-installation-guide/17#installation-2 ':target=_blank')

```bash
wget -O /tmp/install_raspiaudio.sh mic.raspiaudio.com
wget -O /tmp/test_raspiaudtio.sh test.raspiaudio.com
```

Review the scripts `/tmp/install_raspiaudio.sh` and `/tmp/test_raspiaudio.sh` before you proceed.

```bash
bash /tmp/install_raspiaudio.sh
```

The script will ask you to reboot the Pi. After the reboot run the test script. According to the docs this step is
necessary to actually enable the Audio HAT as a sound card.

```bash
bash /tmp/test_raspiaudio.sh
```

### Rotary Encoders

Add this snippet to `/boot/config.txt` on the RPi to enable input events from the rotary encoders. This is based on
the pin mapping I used. If you change the pin mapping, make sure up change the values in `/boot/config.txt`. With
this snippet, I only need to handle the rotation events. The click actions directly emit the configured keyboard
input event and there is nothing more to do.

```
# Setup Rotary Encoders
dtoverlay=rotary-encoder,pin_a=10,pin_b=9,relative_axis=1
dtoverlay=rotary-encoder,pin_a=7,pin_b=8,relative_axis=1
dtoverlay=rotary-encoder,pin_a=17,pin_b=27,relative_axis=1
dtoverlay=rotary-encoder,pin_a=2,pin_b=3,relative_axis=1

dtoverlay=gpio-key,gpio=11,keycode=16,label="KEY_Q"
dtoverlay=gpio-key,gpio=24,keycode=25,label="KEY_P"
dtoverlay=gpio-key,gpio=22,keycode=49,label="KEY_N"
dtoverlay=gpio-key,gpio=4,keycode=50,label="KEY_M"
```

?> You have to use sudo to edit `/boot/config.txt`.
   ```sudo vim /boot/config.txt```

To handle the rotation events of the encoders I wrote a simple python script to be run as a background service.
Next we will configure and enable this service.

Create a python virtual env and add the `evdev` pip module

```bash
python -m venv ~/.venvs/radio
source ~/.venvs/radio/bin/activate
python -m pip install evdev
```

Add the systemd service definition

```bash
sudo cp ~/pi-world-radio/files/etc/systemd/system/gpio_radio_controller.service /etc/systemd/system
sudo systemctl daemon-reload && sudo systemctl enable gpio_radio_controller.service
```
?> Make sure you update the various paths inside the service definition to match your setup

### Display

For the display to work correcly, add this snippet to `/boot/config.txt`

```
# --- start elecrow-pitft-setup  ---
hdmi_force_hotplug=1
max_usb_current=1
hdmi_drive=1
hdmi_group=2
hdmi_mode=1
hdmi_mode=87
hdmi_cvt 800 480 60 6 0 0 0
dtoverlay=ads7846,cs=1,penirq=25,penirq_pull=2,speed=50000,keep_vref_on=0,swapxy=0,pmax=255,xohms=150,xmin=200,xmax=3900,ymin=200,ymax=3900
display_rotate=0
# --- end elecrow-pitft-setup  ---
```

Reboot the RPi to pick up all the changes. If everything worked correctly you should see the console output on the
5" display.

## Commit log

2023-08-08 Add the Rotary encoder controller
2023-08-21 Merged all javascript into single file
    - Move around GPIO assignment to better suit the final assembly
    - Add feature to turn off display on idle
    - Add fourth rotary encoder for dedicated volume control.
2023-08-31 STLs for 3D Printing and Fusion360 project
    [PiRetroRadio.f3d, pi_retro_radio_front_face.stl, pi_retro_radio_screen_mount_left.stl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]
